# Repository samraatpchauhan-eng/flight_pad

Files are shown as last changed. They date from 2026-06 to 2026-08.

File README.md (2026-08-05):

# Flight Pad (RP2040 Custom Macro Pad)



Flight Pad is a custom 3x3 mechanical macro pad featuring dual EC11 rotary encoders, built entirely on the high-performance **Raspberry Pi RP2040** microcontroller architecture and powered by **QMK Firmware**. 

It is designed to streamline flight simulator camera controls, and media navigation with zero-latency input processing.

## Features:
* **Custom Layout:** 3x3 Matrix Grid + 1 Integrated Encoder Switch (10 Keys Total).
* **Dual Encoders:** Dual EC11 Encoders for precise, media adjustments (like brightness, or volume).
* **Ergonomic Design:** Engineered for comfortable desktop use.
* **RP2040 Power:** Driven by the RP2040 chip for rapid response times and effortless flashing.

---

## CAD Model & Case Assembly
Everything fits together precisely using a layered enclosure design. The case includes structural mounting points for the PCB, plates, and components to ensure zero deck-flex during heavy use. Please note the keycaps used in these renders are generic .STEP models downloaded from the internet, and any standard MX keycap should work.

### Case Assembly & Fitment Exploded View
*An isometric 3D CAD visualization highlighting how the PCB, switches, encoders, and structural enclosure layers interface together seamlessly.*

flight_pad_2026-Jun-16_03-59-39AM-000_CustomizedView15204062208

Case_Assembly Fitment3

Case_Assembly Fitment2

Case_Assembly Fitment1

---

## PCB Design
The underlying electronics were engineered in KiCad. The board features clean routing paths optimized for the RP2040 pin configurations and a solid matrix layout to handle both the key switches and rotary encoders.

### Schematic Design
*The underlying circuit schematic mapping the switch matrix routing, diode placement, and dual encoder connections to the microcontroller.*

Electrical_Schematic_Diagram

### PCB Layout Architecture
*The routed printed circuit board design detailing trace paths, footprints, and physical alignment.*



---

## Firmware Overview & Default Keymap
This macro pad utilizes **QMK Firmware** for all input processing. The keys are configured in a standard matrix, while the encoders are tracked using hardware interrupts for maximum precision.

### Key Matrix (3x3 Grid)
| Row | Column 1 | Column 2 | Column 3 |
| :--- | :---: | :---: | :---: |
| **Row 0** | `Ctrl+6` | `Ctrl+1` | `Ctrl+7` |
| **Row 1** | `Ctrl+9` | `Ctrl+5` | `Ctrl+8` |
| **Row 2** | `L` | `C` | `R` |

### Rotary Encoder Functionality
* **Encoder 1 (Left/Volume):** * Clockwise: `Volume Up` | Counter-Clockwise: `Volume Down`
  * Integrated Push Switch: `MUTE`
* **Encoder 2 (Right/Brightness):** * Clockwise: `Screen Brightness Down` | Counter-Clockwise: `Screen Brightness Up`

---

## Bill of Materials (BOM)
Here is the complete component breakdown required to build the Flight Pad:

* **9x** Cherry MX Mechanical Switches
* **9x** MX-Compatible Keycaps
* **9x** 1N4148 DO-35 Switching Diodes *(Crucial for matrix isolation and anti-ghosting)*
* **2x** EC11 Rotary Encoders with integrated push-switches
* **1x** Raspberry Pi RP2040 Microcontroller Board
* **1x** Custom Case Enclosure (3D printed/CNC components)
* **4x** M3x16mm screws
* **1x** USB-C wire with data transfer

---

## How to Flash
1. Disconnect the USB cable from the Flight Pad.
2. Press and hold the physical **BOOT** button on the RP2040 controller board.
3. Reconnect the USB cable while holding the button, then release it.
4. A virtual drive named **RPI-RP2** will mount to your operating system.
5. Drag and drop the `flight_pad_default.uf2` binary file directly onto the root of the drive.
6. The device will automatically flash, reboot, and initialize as an operational HID keyboard device.

---

## AI Attribution Note
**Please Note that AI was utilized for some basic debugging of the Keyboard.JSON, and Keymap.C files in VS.Code**

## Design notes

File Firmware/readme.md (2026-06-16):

# flight_pad

flight_pad

*A short description of the keyboard/project*

* Keyboard Maintainer: [Samraat Chauhan](https://github.com/samraatpchauhan-eng)
* Hardware Supported: *The PCBs, controllers supported*
* Hardware Availability: *Links to where you can find this hardware*

Make example for this keyboard (after setting up your build environment):

    make flight_pad:default

Flashing example for this keyboard:

    make flight_pad:default:flash

See the [build environment setup](https://docs.qmk.fm/#/getting_started_build_tools) and the [make instructions](https://docs.qmk.fm/#/getting_started_make_guide) for more information. Brand new to QMK? Start with our [Complete Newbs Guide](https://docs.qmk.fm/#/newbs).

## Bootloader

Enter the bootloader in 3 ways:

* **Bootmagic reset**: Hold down the key at (0,0) in the matrix (usually the top left key or Escape) and plug in the keyboard
* **Physical reset button**: Briefly press the button on the back of the PCB - some may have pads you must short instead
* **Keycode in layout**: Press the key mapped to `QK_BOOT` if it is available

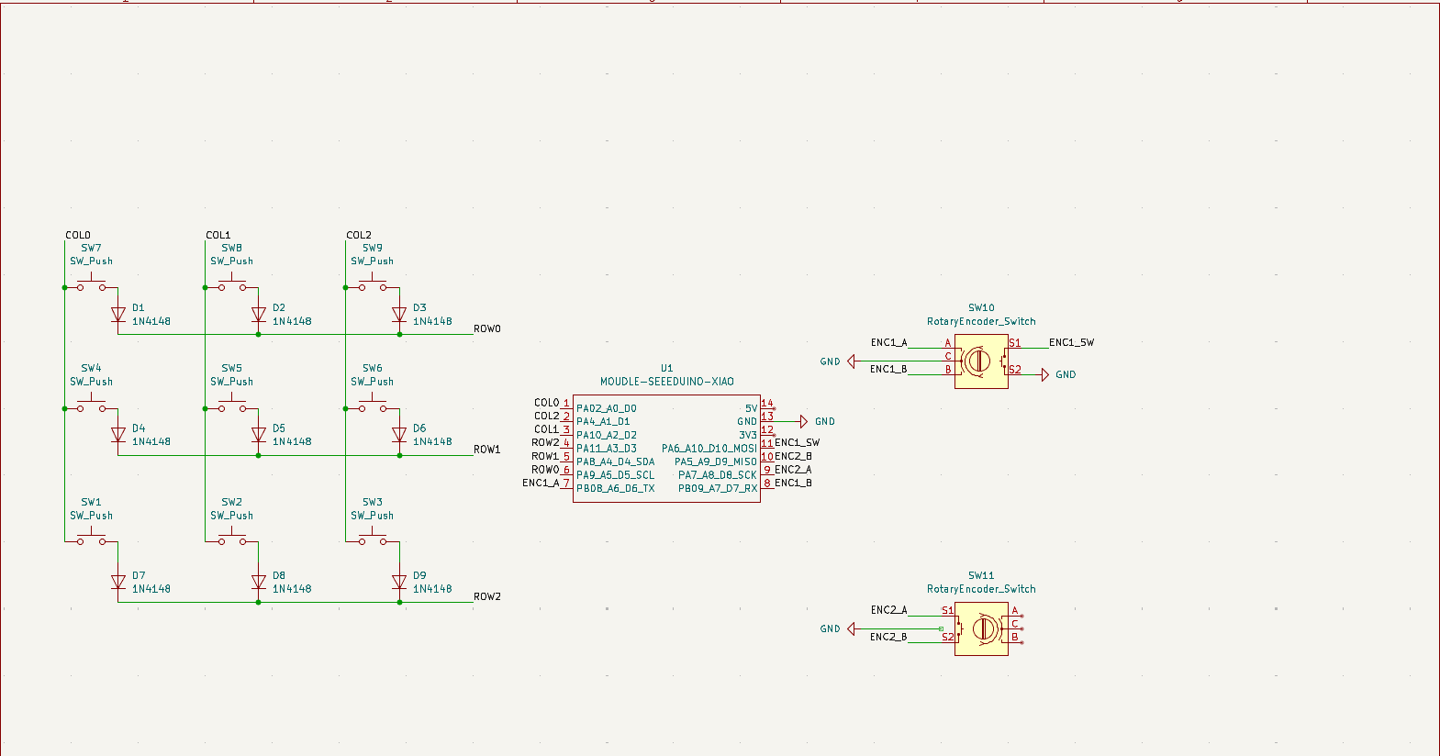
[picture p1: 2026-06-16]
Electrical_Schematic_Diagram.png

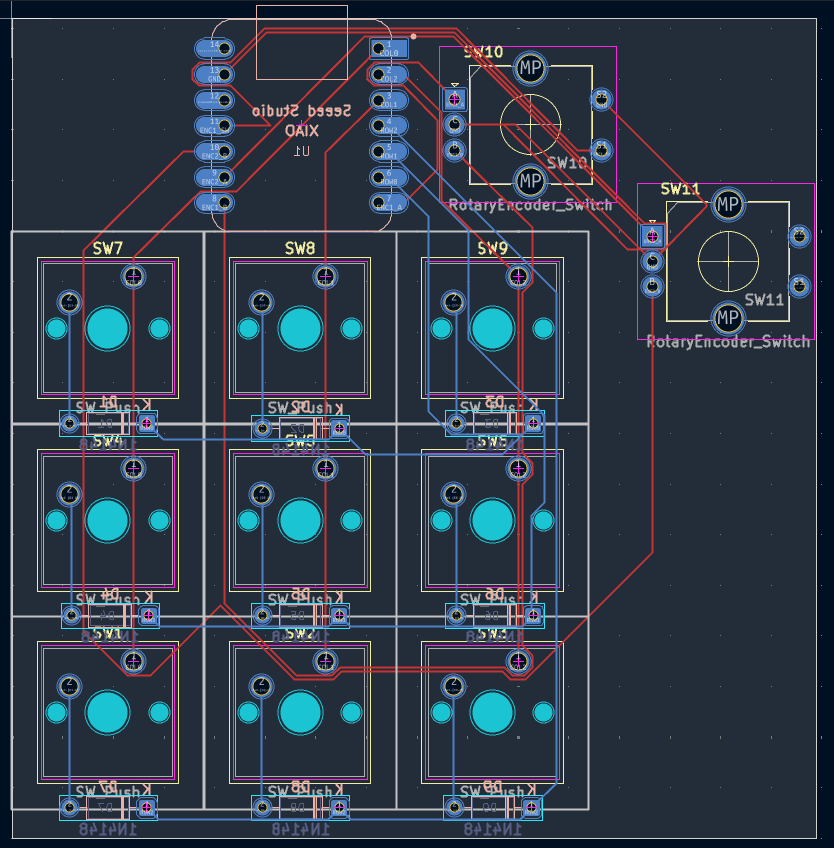
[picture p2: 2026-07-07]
PCB-Layout.png

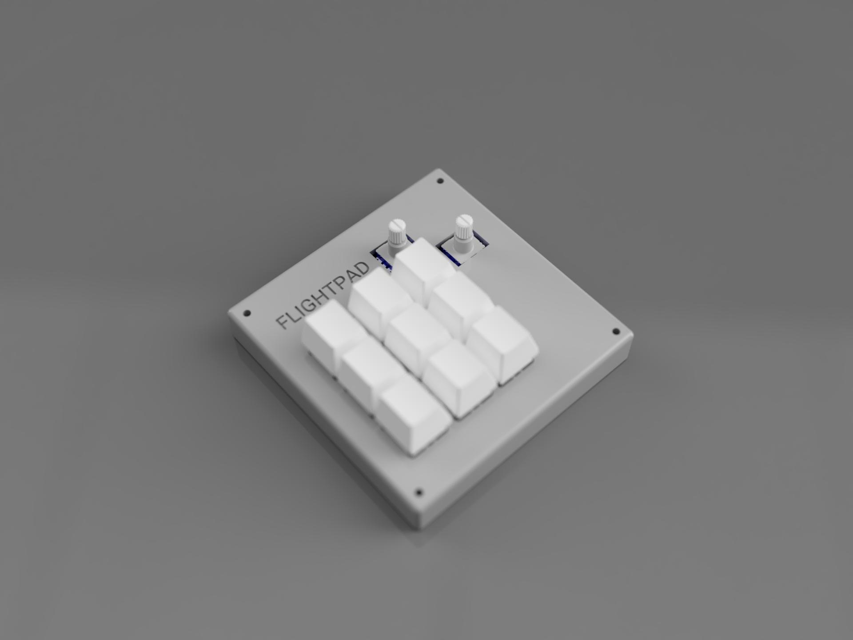
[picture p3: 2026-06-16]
flight_pad_2026-Jun-16_03-59-39AM-000_CustomizedView15204062208.jpg

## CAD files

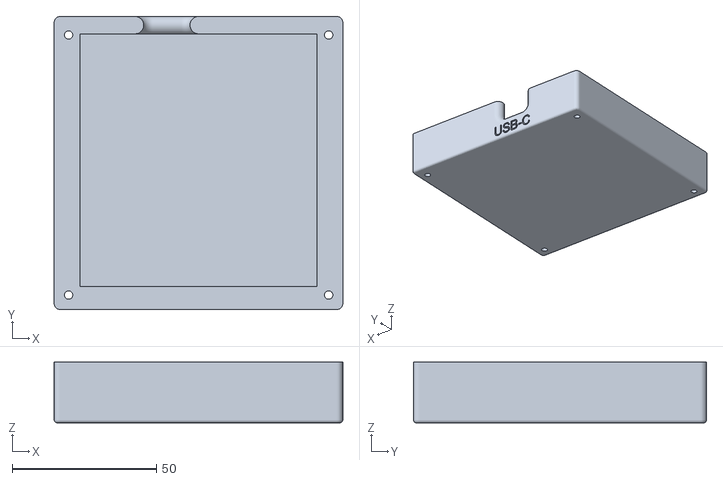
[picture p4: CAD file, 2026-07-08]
Production/Bottom_V2.stl
99.9 x 101.4 x 21.0

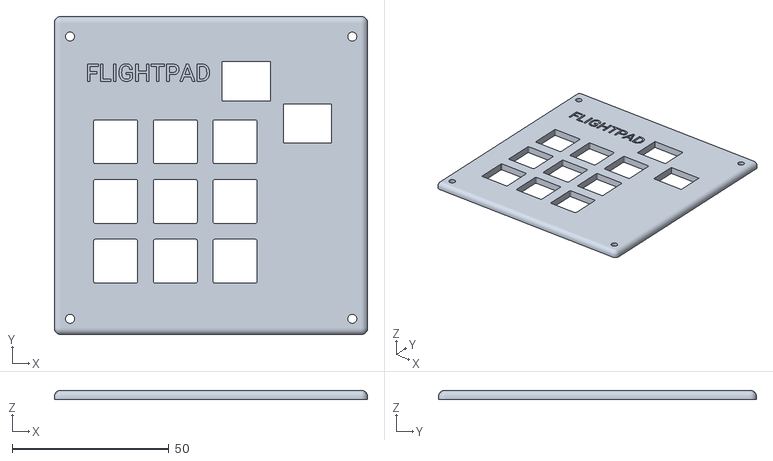
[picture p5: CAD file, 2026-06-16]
Production/Top.stl
99.9 x 101.4 x 3.00

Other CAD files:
CAD/flight_pad.f3z

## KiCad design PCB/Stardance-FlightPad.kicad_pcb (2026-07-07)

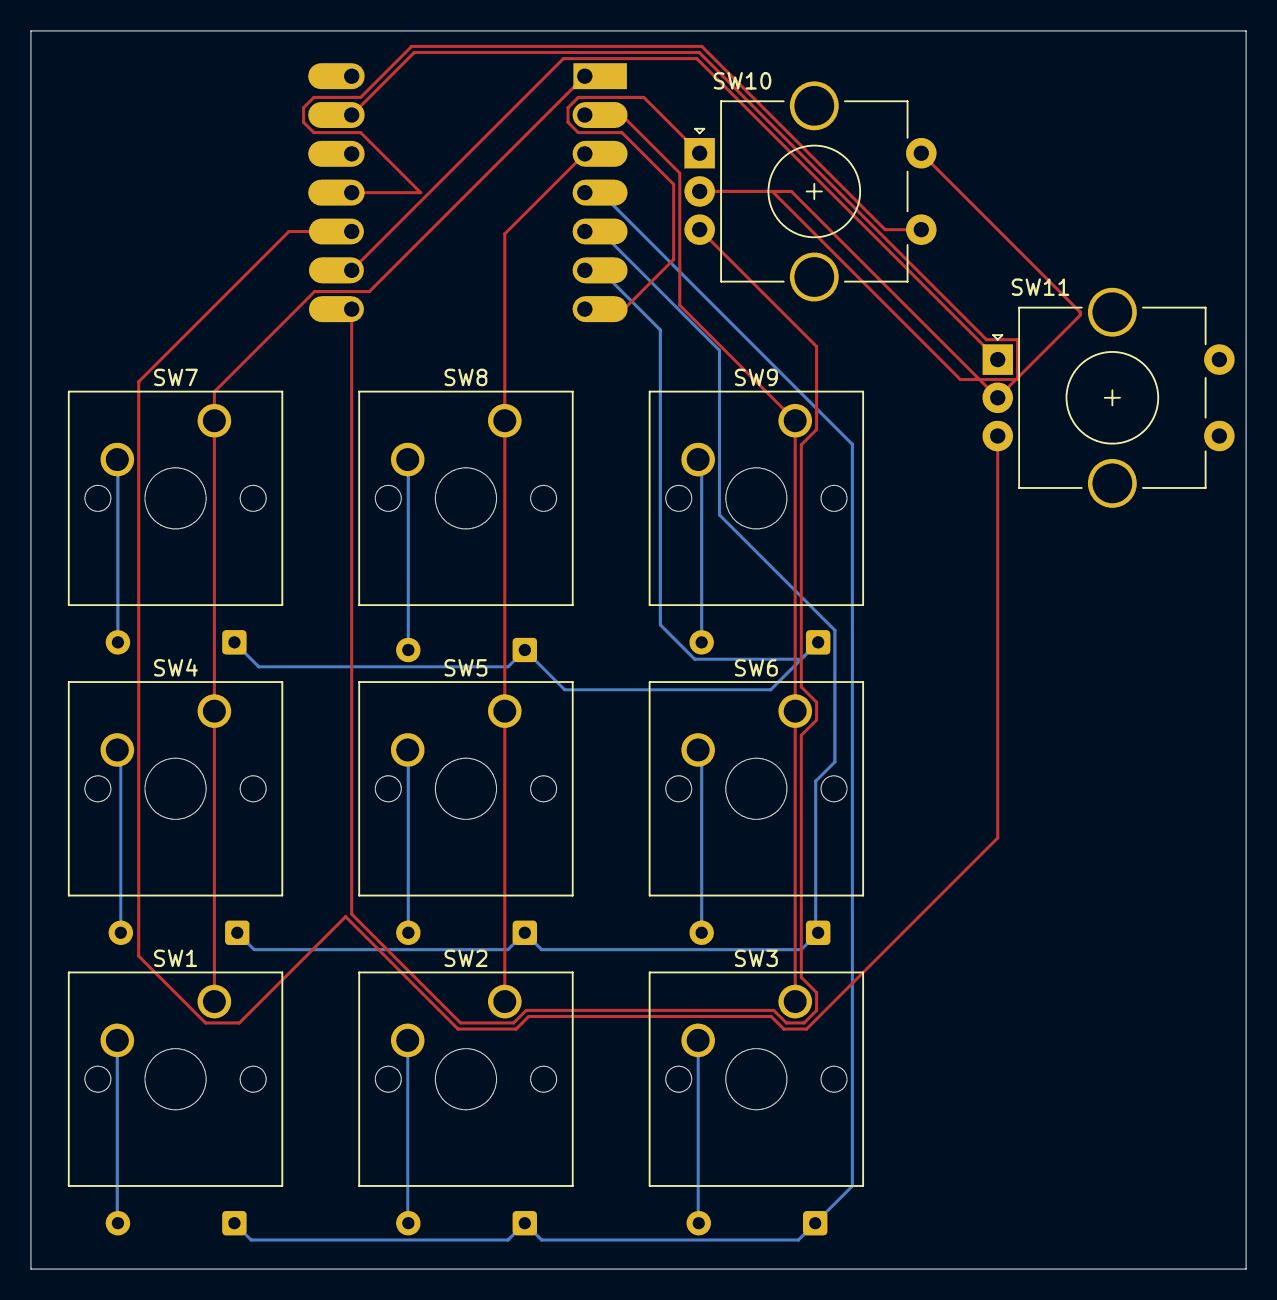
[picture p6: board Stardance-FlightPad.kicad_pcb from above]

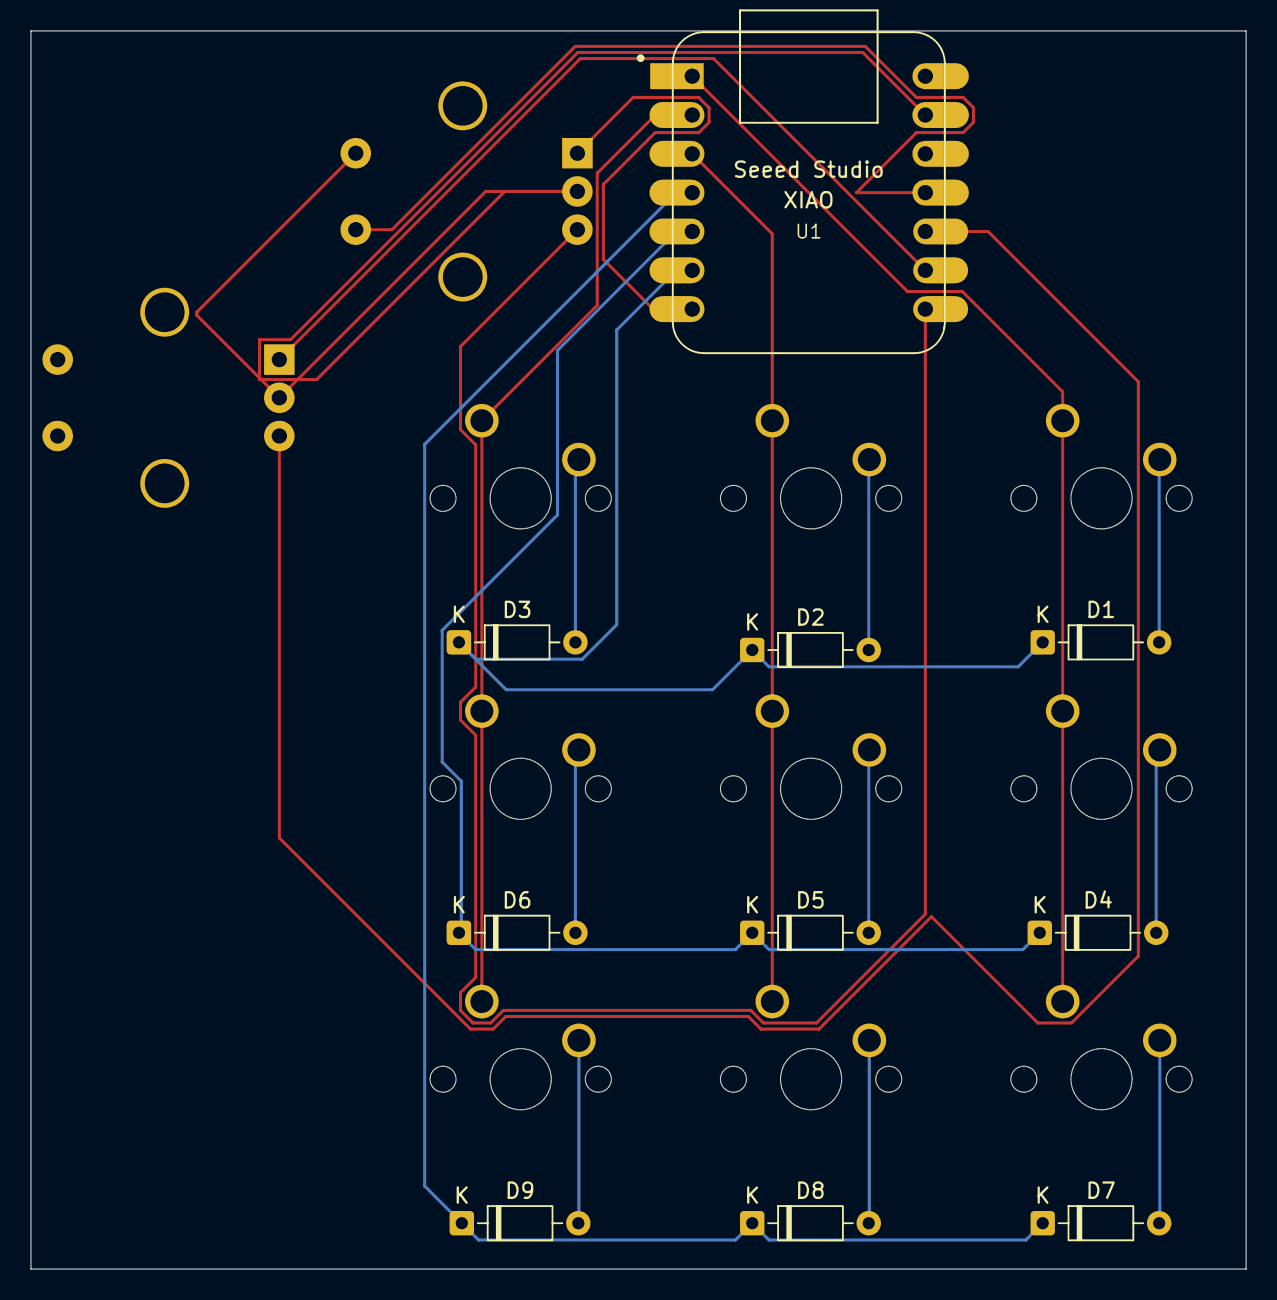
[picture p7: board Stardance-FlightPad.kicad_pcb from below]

Board: 2 copper layers, 79.5 x 81.0 mm, 21 parts (10 on the bottom side), 21 nets.

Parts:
D1, D2, D3, D4, D5, D6, D7, D8, D9: 1N4148; D_DO-35_SOD27_P7.62mm_Horizontal
SW1, SW2, SW3, SW4, SW5, SW6, SW7, SW8, SW9: SW_Push; SW_Cherry_MX_1.00u_PCB
SW10, SW11: RotaryEncoder_Switch; RotaryEncoder_Alps_EC11E-Switch_Vertical_H20mm_CircularMoun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
U1: MOUDLE-SEEEDUINO-XIAO; XIAO-Generic-Hybrid-14P-2.54-21X17.8MM

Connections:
/COL0: SW1.1, SW4.1, SW7.1, U1.1 (PA02_A0_D0)
/COL1: SW2.1, SW5.1, SW8.1, U1.3 (PA10_A2_D2)
/COL2: SW3.1, SW6.1, SW9.1, U1.2 (PA4_A1_D1)
/ENC1_A: SW10.A, U1.7 (PB08_A6_D6_TX)
/ENC1_B: SW10.B, U1.8 (PB09_A7_D7_RX)
/ENC1_SW: SW10.S1, U1.11 (PA6_A10_D10_MOSI)
/ENC2_A: SW11.A, U1.9 (PA7_A8_D8_SCK)
/ENC2_B: SW11.B, U1.10 (PA5_A9_D9_MISO)
/ROW0: D1.1 (K), D2.1 (K), D3.1 (K), U1.6 (PA9_A5_D5_SCL)
/ROW1: D4.1 (K), D5.1 (K), D6.1 (K), U1.5 (PA8_A4_D4_SDA)
/ROW2: D7.1 (K), D8.1 (K), D9.1 (K), U1.4 (PA11_A3_D3)
GND: SW10.C, SW10.S2, SW11.C, U1.13 (GND)
unnamed: D1.2 (A), SW7.2
unnamed: D2.2 (A), SW8.2
unnamed: D3.2 (A), SW9.2
unnamed: D4.2 (A), SW4.2
unnamed: D5.2 (A), SW5.2
unnamed: D6.2 (A), SW6.2
unnamed: D7.2 (A), SW1.2
unnamed: D8.2 (A), SW2.2
unnamed: D9.2 (A), SW3.2

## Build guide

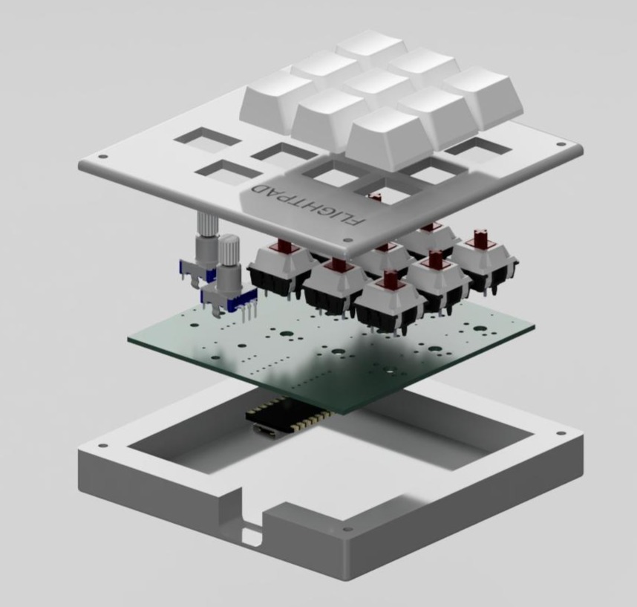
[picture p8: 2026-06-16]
Case_Assembly&Fitment1.jpg

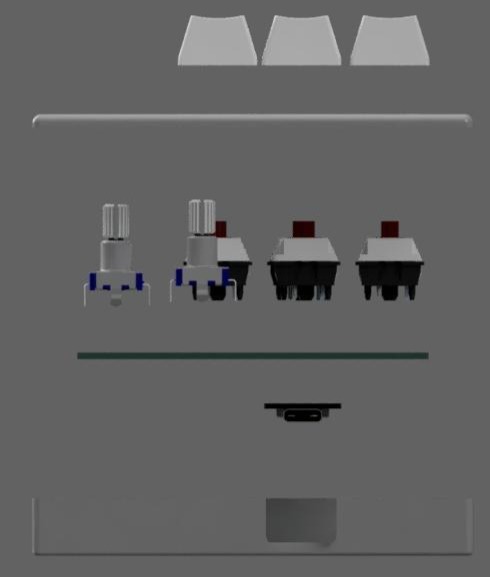
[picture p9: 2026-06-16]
Case_Assembly&Fitment3.jpg

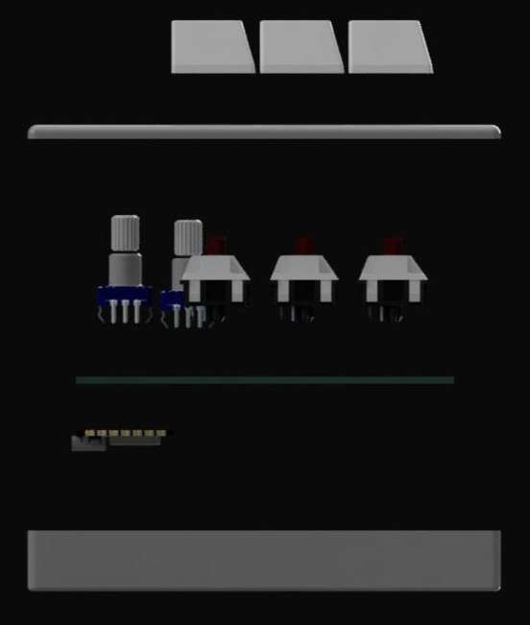
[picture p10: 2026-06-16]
Case_Assembly&Fitment2.jpg

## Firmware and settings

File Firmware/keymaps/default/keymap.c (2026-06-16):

// Copyright 2026 QMK
// SPDX-License-Identifier: GPL-2.0-or-later

#include QMK_KEYBOARD_H

const uint16_t PROGMEM keymaps[][MATRIX_ROWS][MATRIX_COLS] = {
    /*
     * ┌───┬───┬───┐
     * │ A │ B │ C │
     * ├───┼───┼───┤
     * │ D │ E │ F │
     * ├───┼───┼───┤
     * │ G │ H │ I │
     * └───┴───┴───┘
     * │MUTE │ <-- Encoder Push Switch
     * └─────┘
     */
    [0] = LAYOUT_ortho_3x4(
        KC_6,    KC_1,    KC_7,
        KC_9,    KC_5,    KC_8,
        KC_L,    KC_C,    KC_R,
        KC_MUTE
    )
};

#ifdef ENCODER_ENABLE
bool encoder_update_user(uint8_t index, bool clockwise) {
    if (index == 0) {
        // First encoder: Volume Control
        if (clockwise) {
            tap_code(KC_VOLU);
        } else {
            tap_code(KC_VOLD);
        }
    } else if (index == 1) {
        // Second encoder: Page Scrolling
        if (clockwise) {
            tap_code(KC_PGDN);
        } else {
            tap_code(KC_PGUP);
        }
    }
    return true;
}
#endif

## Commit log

2026-06-16 Revise README with comprehensive project details
    Expanded README to include detailed features, assembly instructions, PCB design, firmware overview, and BOM for the Flight Pad project.
2026-06-16 Add PCB Layout image to README
2026-06-27 Update components list in README
    Added USB-C wire with data transfer to the components list.
2026-07-04 changed cad file formats
    [flight_pad.f3z, flight_pad.step]
2026-07-07 Revised some Cad files
    [Bottom.stl, flight_pad.f3z]
2026-07-07 Fixed routing errors in pcb
    [Stardance-FlightPad.kicad_pcb]
2026-07-07 Replace PCB layout image in README
    Updated PCB layout image to a new screenshot.
2026-07-07 Revised PCB layout pic and readme
2026-07-08 Updated Bottom
    [Bottom.stl, Bottom_V2.stl]
